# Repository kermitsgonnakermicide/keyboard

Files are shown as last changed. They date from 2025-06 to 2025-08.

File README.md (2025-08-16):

# keyboard

a travel sized 60% keyboard with two rotary encoders for extra functionality!<br>

## Design<br>

This keyboard is pretty **bog-standard**, and can be split into two basic components; the PCB and case<br>
**PCB**:<br>
Fully through hole, with a raspberry pi pico, in4018 diodes and HMX macchiato switches(cheap + sound awesome!)<br>
Went fully THT to keep costs as low as I can, and get some real soldering in!<br>
**Case**:<BR>
Just a case covering the entire keyboard t_t
Again, owing to the purpose of the keyboard, I want to keep it small and simple, but for the shiggles I addded this cool pattern to the bottom of my case<br>
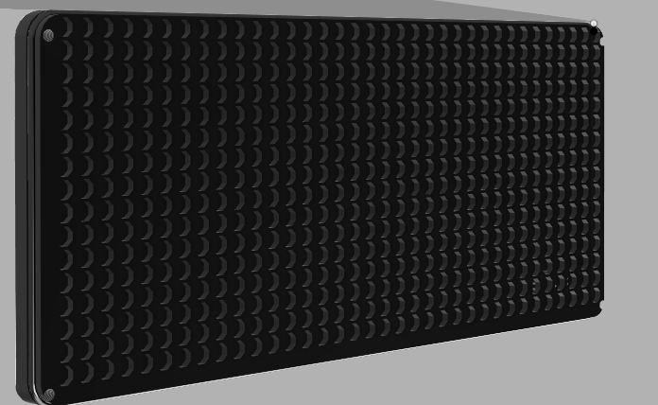
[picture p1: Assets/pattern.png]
<br>

**Firmware**:<br>
Again, pretty standard KMK firmware running on the pico<br>
<br>

## Images

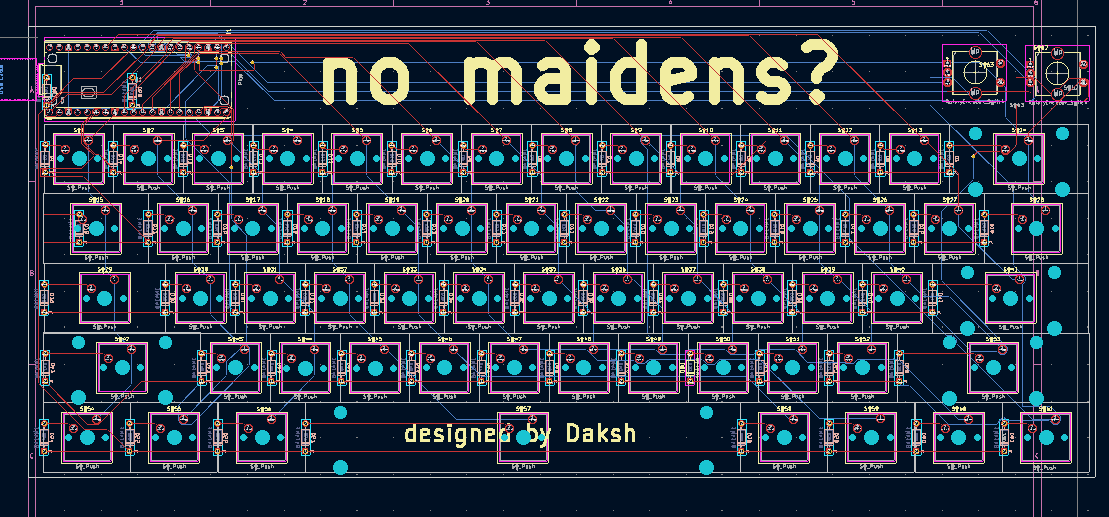
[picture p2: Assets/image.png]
<br>
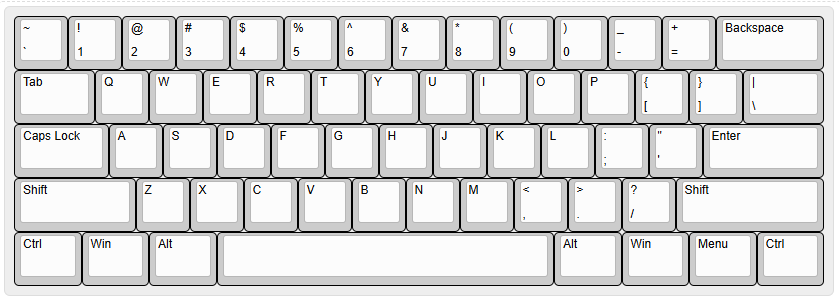
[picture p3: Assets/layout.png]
<br>
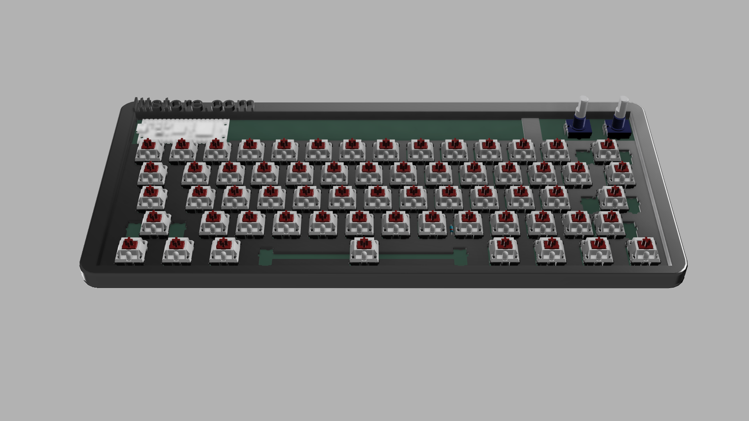
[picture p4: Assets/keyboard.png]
<BR>
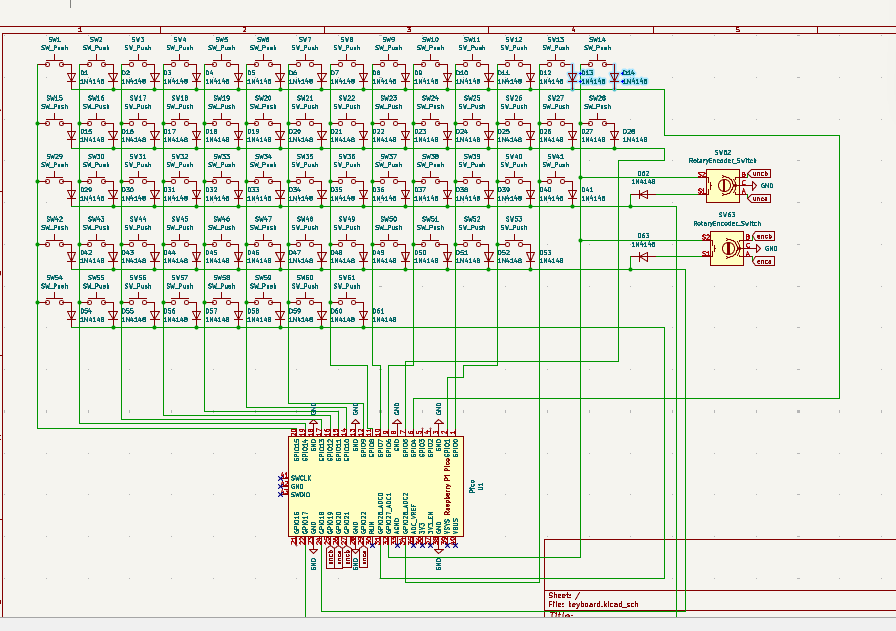
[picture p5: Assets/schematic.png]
<br>

### Images of the CAD

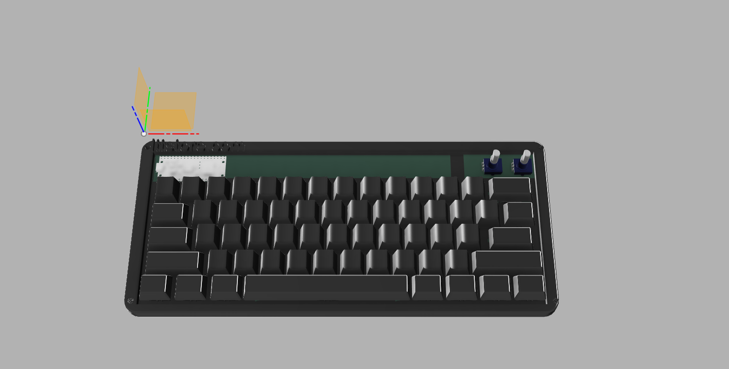
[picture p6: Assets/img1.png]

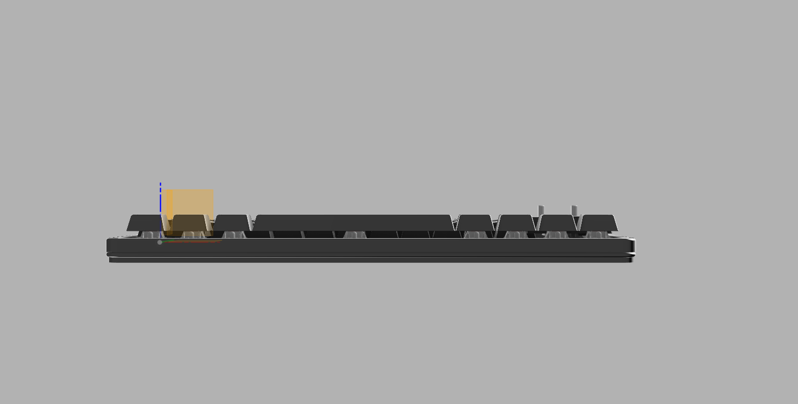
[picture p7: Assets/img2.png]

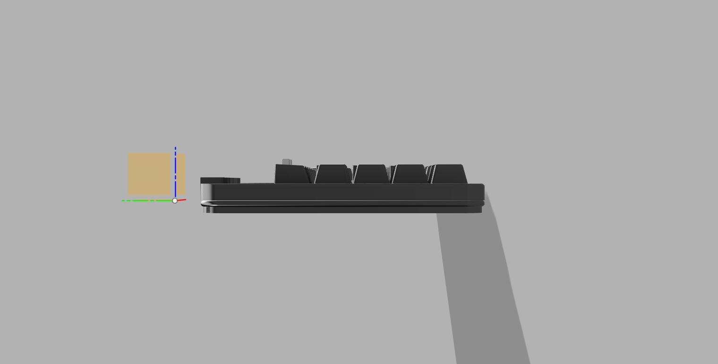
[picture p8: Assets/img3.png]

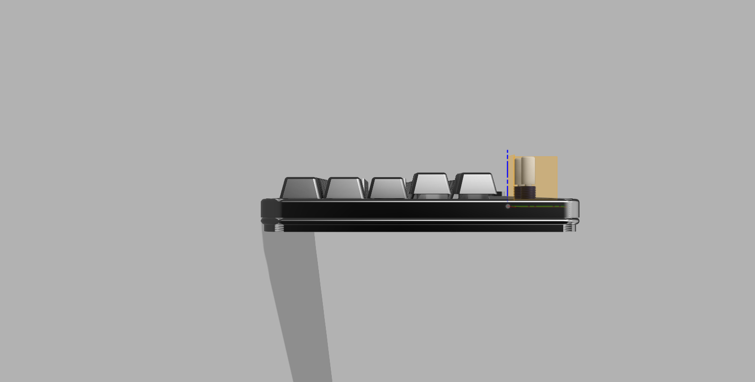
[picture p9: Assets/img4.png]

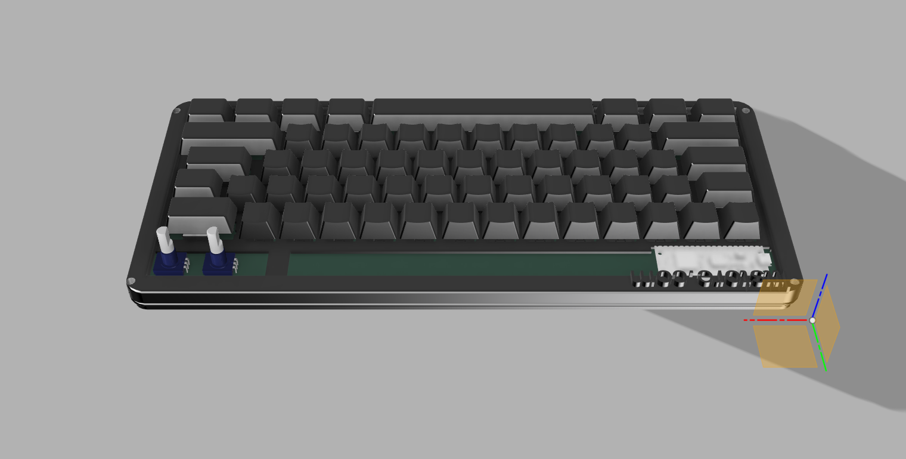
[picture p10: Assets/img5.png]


## BOM

| ITEM | QTY | TOTAL  | SRC | NOTE |
| --- | --- | --- | --- | --- |
| HMX Macchiato Linear Switch | 7 | 24.35  | [https://neomacro.in/products/keykobo-rainbow?variant=48680982413590](https://neomacro.in/products/keykobo-rainbow?variant=48680982413590) | Sold in packs of 10 and I require 62 |
| KeyKobo Rainbow Keycap | 1 | 43.48  | [https://neomacro.in/products/keykobo-rainbow?variant=48680982413590](https://neomacro.in/products/keykobo-rainbow?variant=48680982413590) | |
| Raspberry Pi Pico 2 | 1 | 4.79 | [https://www.amazon.in/Raspberry-Pico-All-Microcontroller-Board/dp/B0B69KZBD8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,aps,281&sr=8-1&th=1](https://www.amazon.in/Raspberry-Pico-All-Microcontroller-Board/dp/B0B69KZBD8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,aps,281&sr=8-1&th=1) | |
| IN4148 diode | 100 | 1.74 | [https://www.amazon.in/100PCS-1N4148-IN4148-switching-Switching/dp/B08DYFFYPQ](https://www.amazon.in/100PCS-1N4148-IN4148-switching-Switching/dp/B08DYFFYPQ) | |
| EC11 Encoder | 2 | 2.06 | [https://www.amazon.in/dp/B0888RVZSN?social_share=cm_sw_r_cp_ud_dp_ECM6496E6Q914JPQP2XQ&\_encoding=UTF8&psc=1](https://www.amazon.in/dp/B0888RVZSN?social_share=cm_sw_r_cp_ud_dp_ECM6496E6Q914JPQP2XQ&_encoding=UTF8&psc=1) | |
| PCB Cost | 1 | 39.55  | JLCPCB | Without coupon, including shipping |
| M5 CSK Screws | 15  | 1.71 | [https://www.amazon.in/RT-SENSE-Countersunk-Machine-tensile/dp/B0CZDXM5NJ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,industrial,263&sr=1-4&th=1](https://www.amazon.in/RT-SENSE-Countersunk-Machine-tensile/dp/B0CZDXM5NJ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,industrial,263&sr=1-4&th=1) | |
| | | | | |
| | | 117.68 | | |

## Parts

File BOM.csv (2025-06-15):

ITEM | QTY | TOTAL | SRC | NOTE
HMX Macchiato Linear Switch | 7 | 24.35 | https://neomacro.in/products/keykobo-rainbow?variant=48680982413590 | Sold in packs of 10 and I require 62
KeyKobo Rainbow Keycap | 1 | 43.48 | https://neomacro.in/products/keykobo-rainbow?variant=48680982413590
Raspberry Pi Pico 2 | 1 | 9.76 | https://www.amazon.in/Raspberry-Microcontroller-Dual-Core-Support-Performance/dp/B0DT983C25
IN4148 diode | 100 | 1.74 | https://www.amazon.in/100PCS-1N4148-IN4148-switching-Switching/dp/B08DYFFYPQ
EC11 Encoder | 2 | 2.06 | https://www.amazon.in/dp/B0888RVZSN
PCB Cost | 1 | 39.55 | JLCPCB | Without coupon, including shipping
M5 CSK Screws | 10 | 0.36
 |  | 121.3

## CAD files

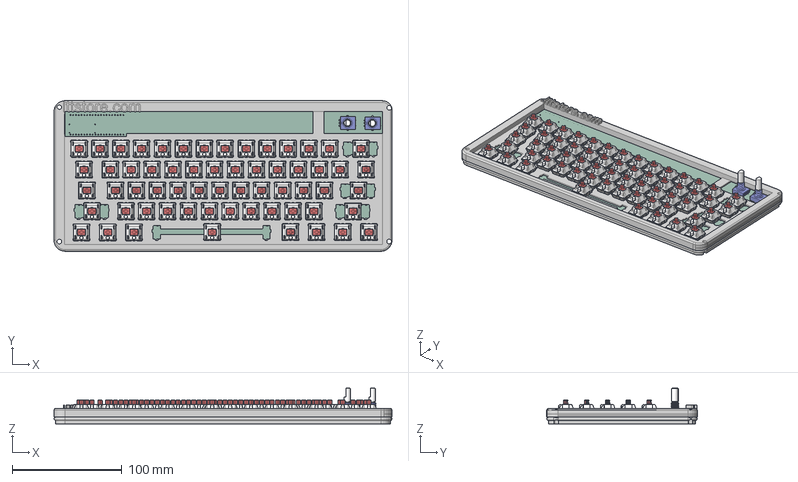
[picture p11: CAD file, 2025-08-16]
keyboard v14.step
308.4 x 137.4 x 32.5 mm
D_DO-35_SOD27_P7.62mm_Horizontal x 63
Bottom x 61
Pulsador x 61
Top x 61
Pieza5^Cherry MX x 61
Pin1 x 61
Pin2 x 61
Led 3mm_trans x 61
Shaft x 2
Pins x 2

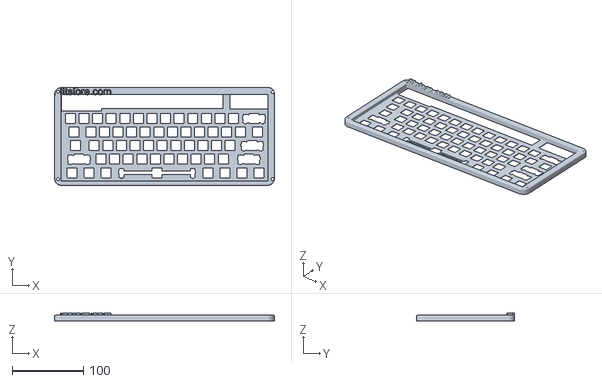
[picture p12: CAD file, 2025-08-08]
Production/top_panel.stl
308.4 x 137.4 x 11.0

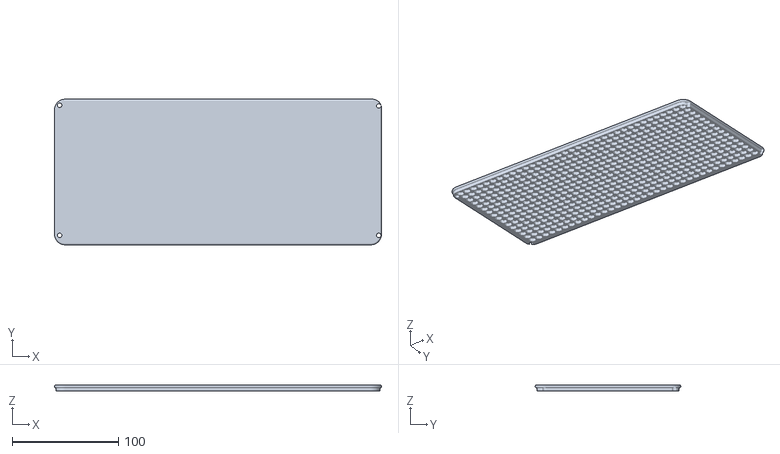
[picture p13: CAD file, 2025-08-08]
Production/bottom_panel.stl
308.4 x 137.4 x 6.00

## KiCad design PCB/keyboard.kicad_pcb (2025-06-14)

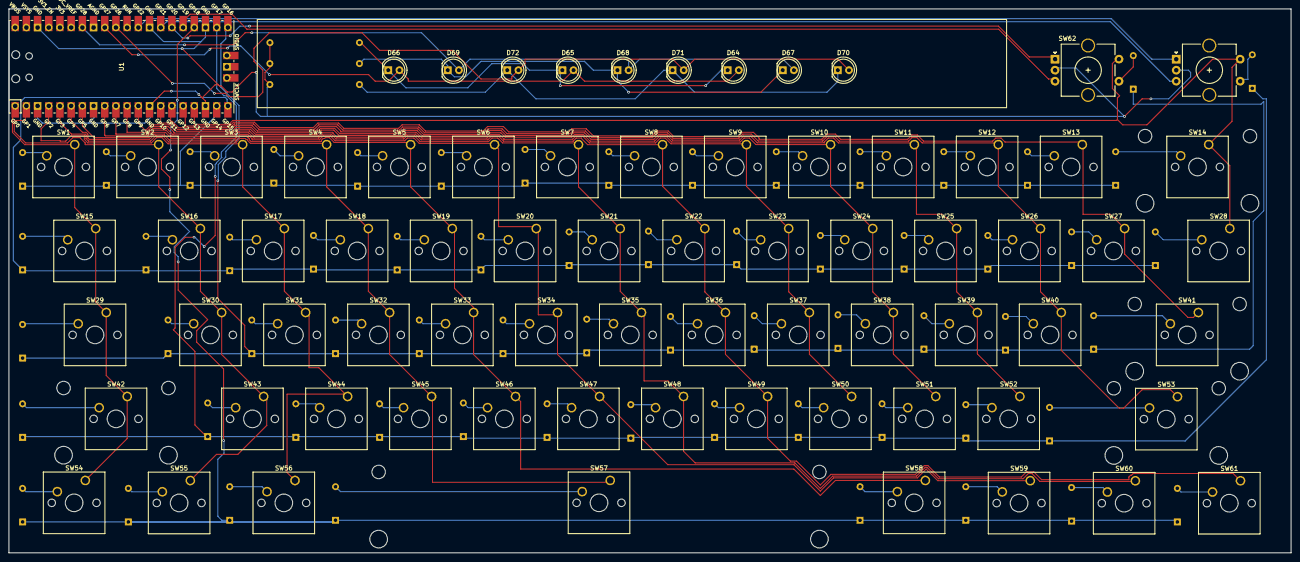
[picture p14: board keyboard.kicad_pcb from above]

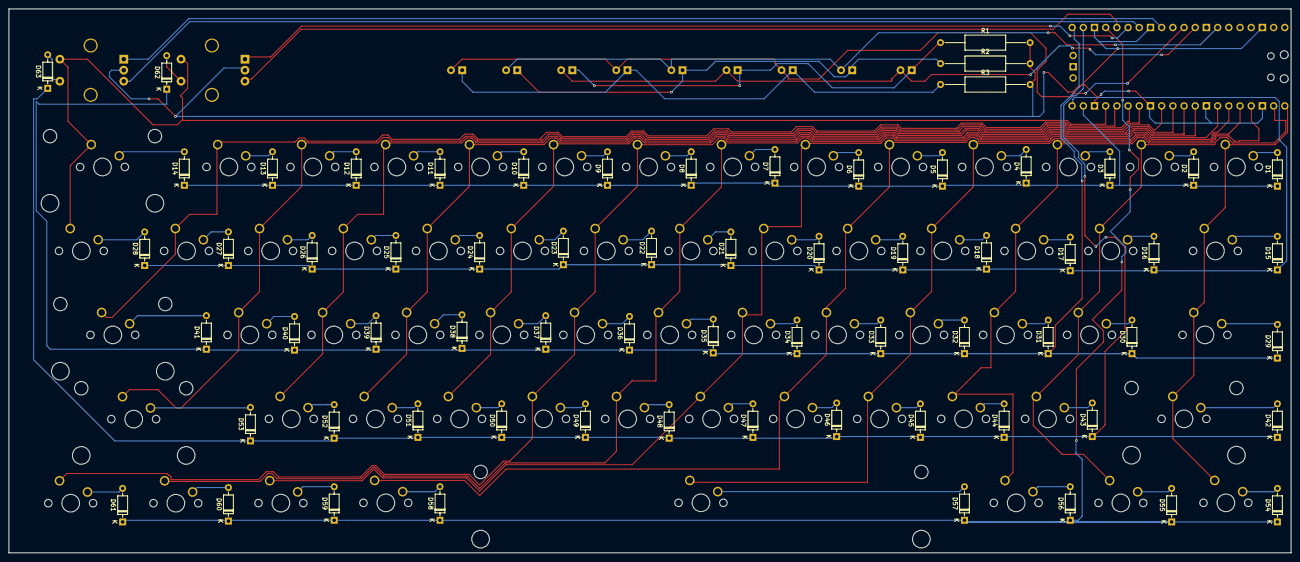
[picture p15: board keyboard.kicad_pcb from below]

Board: 2 copper layers, 290.9 x 123.4 mm, 139 parts (66 on the bottom side), 93 nets.

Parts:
D1, D2, D3, D4, D5, D6, D7, D8, D9, D10, D11, D12, D13, D14, D15, D16, D17, D18, D19, D20, D21, D22, D23, D24, D25, D26, D27, D28, D29, D30, D31, D32, D33, D34, D35, D36, D37, D38, D39, D40, D41, D42, D43, D44, D45, D46, D47, D48, D49, D50, D51, D52, D53, D54, D55, D56, D57, D58, D59, D60, D61, D62, D63: 1N4148; D_DO-35_SOD27_P7.62mm_Horizontal
D64, D65, D66, D67, D68, D69, D70, D71, D72: LED_Small; LED_D5.0mm
R1, R2, R3: 330Ω; R_Axial_DIN0309_L9.0mm_D3.2mm_P20.32mm_Horizontal
SW1, SW2, SW3, SW4, SW5, SW6, SW7, SW8, SW9, SW10, SW11, SW12, SW13, SW16, SW17, SW18, SW19, SW20, SW21, SW22, SW23, SW24, SW25, SW26, SW27, SW30, SW31, SW32, SW33, SW34, SW35, SW36, SW37, SW38, SW39, SW40, SW43, SW44, SW45, SW46, SW47, SW48, SW49, SW50, SW51, SW52: SW_Push; SW_Cherry_MX_1.00u_PCB
SW14: SW_Push; SW_Cherry_MX_2.00u_PCB
SW15, SW28: SW_Push; SW_Cherry_MX_1.50u_PCB
SW29: SW_Push; SW_Cherry_MX_1.75u_PCB
SW41, SW42: SW_Push; SW_Cherry_MX_2.25u_PCB
SW53: SW_Push; SW_Cherry_MX_2.75u_PCB
SW54, SW55, SW56, SW58, SW59, SW60, SW61: SW_Push; SW_Cherry_MX_1.25u_PCB
SW57: SW_Push; SW_Cherry_MX_6.25u_PCB
SW62, SW63: RotaryEncoder_Switch; RotaryEncoder_Alps_EC11E-Switch_Vertical_H20mm_CircularMoun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
U1: Pico; RPi_Pico_SMD_TH

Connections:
GND: R1.2, R2.2, R3.2, SW62.C, SW63.C, U1.3 (GND), U1.8 (GND), U1.13 (GND), U1.18 (GND), U1.23 (GND), U1.28 (GND), U1.38 (GND)
unnamed: D1.2 (A), SW1.2
unnamed: D2.2 (A), SW2.2
unnamed: D3.2 (A), SW3.2
unnamed: D4.2 (A), SW4.2
unnamed: D5.2 (A), SW5.2
unnamed: D6.2 (A), SW6.2
unnamed: D7.2 (A), SW7.2
unnamed: D8.2 (A), SW8.2
unnamed: D9.2 (A), SW9.2
unnamed: D10.2 (A), SW10.2
unnamed: D11.2 (A), SW11.2
unnamed: D12.2 (A), SW12.2
unnamed: D13.2 (A), SW13.2
unnamed: D14.2 (A), SW14.2
unnamed: D15.2 (A), SW15.2
unnamed: D16.2 (A), SW16.2
unnamed: D17.2 (A), SW17.2
unnamed: D18.2 (A), SW18.2
unnamed: D19.2 (A), SW19.2
unnamed: D20.2 (A), SW20.2
unnamed: D21.2 (A), SW21.2
unnamed: D22.2 (A), SW22.2
unnamed: D23.2 (A), SW23.2
unnamed: D24.2 (A), SW24.2
unnamed: D25.2 (A), SW25.2
unnamed: D26.2 (A), SW26.2
unnamed: D27.2 (A), SW27.2
unnamed: D28.2 (A), SW28.2
unnamed: D29.2 (A), SW29.2
unnamed: D30.2 (A), SW30.2
unnamed: D31.2 (A), SW31.2
unnamed: D32.2 (A), SW32.2
unnamed: D33.2 (A), SW33.2
unnamed: D34.2 (A), SW34.2
unnamed: D35.2 (A), SW35.2
unnamed: D36.2 (A), SW36.2
unnamed: D37.2 (A), SW37.2
unnamed: D38.2 (A), SW38.2
unnamed: D39.2 (A), SW39.2
unnamed: D40.2 (A), SW40.2
unnamed: D41.2 (A), SW41.2
unnamed: D42.2 (A), SW42.2
unnamed: D43.2 (A), SW43.2
unnamed: D44.2 (A), SW44.2
unnamed: D45.2 (A), SW45.2
unnamed: D46.2 (A), SW46.2
unnamed: D47.2 (A), SW47.2
unnamed: D48.2 (A), SW48.2
unnamed: D49.2 (A), SW49.2
unnamed: D50.2 (A), SW50.2
unnamed: D51.2 (A), SW51.2
unnamed: D52.2 (A), SW52.2
unnamed: D53.2 (A), SW53.2
unnamed: D54.2 (A), SW54.2
unnamed: D55.2 (A), SW55.2
unnamed: D56.2 (A), SW56.2
unnamed: D57.2 (A), SW57.2
unnamed: D58.2 (A), SW58.2
unnamed: D59.2 (A), SW59.2
unnamed: D60.2 (A), SW60.2
unnamed: D61.2 (A), SW61.2
unnamed: D62.2 (A), SW62.S1
unnamed: D63.2 (A), SW63.S1
unnamed: D64.1 (K), D65.1 (K), D66.1 (K), R1.1
unnamed: D67.1 (K), D68.1 (K), D69.1 (K), R2.1
unnamed: D70.1 (K), D71.1 (K), D72.1 (K), R3.1
blue_anode: D67.2 (A), D68.2 (A), D69.2 (A), U1.34 (GPIO28_ADC2)
col1: SW1.1, SW15.1, SW29.1, SW42.1, SW54.1, U1.1 (GPIO0)
col2: SW2.1, SW16.1, SW30.1, SW43.1, SW55.1, U1.2 (GPIO1)
col3: SW3.1, SW17.1, SW31.1, SW44.1, SW56.1, U1.4 (GPIO2)
col4: SW4.1, SW18.1, SW32.1, SW45.1, SW57.1, U1.5 (GPIO3)
col5: SW5.1, SW19.1, SW33.1, SW46.1, SW58.1, U1.6 (GPIO4)
col6: SW6.1, SW20.1, SW34.1, SW47.1, SW59.1, U1.7 (GPIO5)
col7: SW7.1, SW21.1, SW35.1, SW48.1, SW60.1, U1.9 (GPIO6)
col8: SW8.1, SW22.1, SW36.1, SW49.1, SW61.1, U1.10 (GPIO7)
col9: SW9.1, SW23.1, SW37.1, SW50.1, U1.11 (GPIO8)
col10: SW10.1, SW24.1, SW38.1, SW51.1, U1.12 (GPIO9)
col11: SW11.1, SW25.1, SW39.1, SW52.1, U1.14 (GPIO10)
col12: SW12.1, SW26.1, SW40.1, SW53.1, U1.15 (GPIO11)
col13: SW13.1, SW27.1, SW41.1, U1.16 (GPIO12)
col14: SW14.1, SW28.1, SW62.S2, SW63.S2, U1.17 (GPIO13)
green_anode: D70.2 (A), D71.2 (A), D72.2 (A), U1.31 (GPIO26_ADC0)
re1: SW62.B, U1.25 (GPIO19)
re2: SW62.A, U1.26 (GPIO20)
re3: SW63.B, U1.27 (GPIO21)
re4: SW63.A, U1.29 (GPIO22)
red_anode: D64.2 (A), D65.2 (A), D66.2 (A), U1.32 (GPIO27_ADC1)
row1: D1.1 (K), D2.1 (K), D3.1 (K), D4.1 (K), D5.1 (K), D6.1 (K), D7.1 (K), D8.1 (K), D9.1 (K), D10.1 (K), D11.1 (K), D12.1 (K), D13.1 (K), D14.1 (K), U1.19 (GPIO14)
row2: D15.1 (K), D16.1 (K), D17.1 (K), D18.1 (K), D19.1 (K), D20.1 (K), D21.1 (K), D22.1 (K), D23.1 (K), D24.1 (K), D25.1 (K), D26.1 (K), D27.1 (K), D28.1 (K), U1.20 (GPIO15)
row3: D29.1 (K), D30.1 (K), D31.1 (K), D32.1 (K), D33.1 (K), D34.1 (K), D35.1 (K), D36.1 (K), D37.1 (K), D38.1 (K), D39.1 (K), D40.1 (K), D41.1 (K), D62.1 (K), U1.21 (GPIO16)
row4: D42.1 (K), D43.1 (K), D44.1 (K), D45.1 (K), D46.1 (K), D47.1 (K), D48.1 (K), D49.1 (K), D50.1 (K), D51.1 (K), D52.1 (K), D53.1 (K), D63.1 (K), U1.22 (GPIO17)
row5: D54.1 (K), D55.1 (K), D56.1 (K), D57.1 (K), D58.1 (K), D59.1 (K), D60.1 (K), D61.1 (K), U1.24 (GPIO18)

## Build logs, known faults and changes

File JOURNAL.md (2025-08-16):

**Total Time Spent: 16hr**

# Day 1 - June 13th(PT1)

I decided on a 60% layout, as I wanted this to travel w/ me. I used the default 60% from keyboardlayout <br>
<br>
I also made the schematic for this<br>
<br>
I wanted this keyboard to have two encoders; one for volume dialing and one for general page navigation, so I put them both there<br>
I did use a diode matrix, with through-hole diodes as I wanted to hand-solder this.<BR>
Still not sure on which switches to use, but i'm certain I want something creamy/thocky. Would love to use milky whites or oil kings
**Total Time spent: 4hr**

# Day 2 - June 13th(PT2)

Today, I also routed the PCB for this -<br>
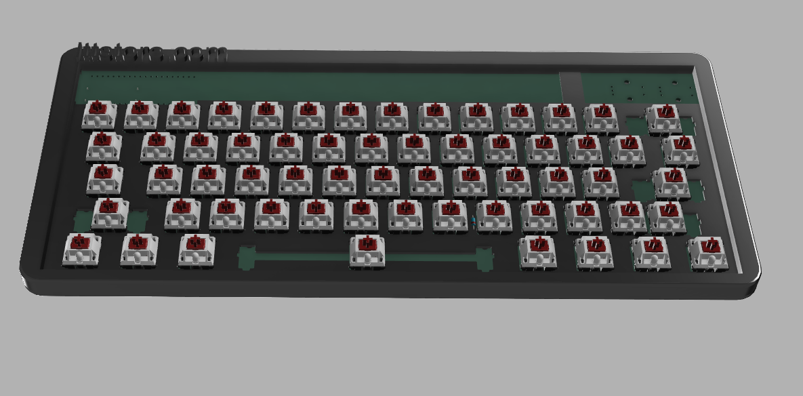
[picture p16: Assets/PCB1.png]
 <br>
Again, I wanted to keep it small as this is a travel keyboard so the dimensions are 292x124mm<br>
This is a rather 'no frills' keyboard - i just want nice switches and a couple encoders and NOTHING else
**Time Spent: 6hr**

# Day 3 - June 14th

Today, I made the case<br>
aaa
The case is(yet again) rather simple, with a couple of slots for m5 size screws to hold the case in place.<br>
Other than that, nothing remarkable except for the fact I intend to use ABS for its durability(remember, this is a travel keyboard)<br>
Additionally, I finally settled on a [switch](https://neomacro.in/products/hmx-macchiato-linear-switch), which is the HMX macchiato and some [keycaps](https://stackskb.com/store/stackspbt-lavender-mda-profile-keycaps-131-key/)
I intend to work on the firmware and _hopefully_ ship it by EOTD<br>
**Time Spent: 3hr30**<br>

# Day 3(pt2)

Firmware was a pretty basic KMK script - everything w/ encoder and keys<br>
Essentially, it uses the row-column diode matrix, same thing with the encoder<br>
KMK runs on Adafruit's circuit python, which will in turn run on my pico
**Time Spent: 1hr30**

# Day 4 - August 16th

Made the cad a little better! Added the keycaps and also a nice hexagon pattern<br>
<br>
The keycaps are for added realism, while the hexagon is just to make the case look cooler<br>






**Time Spent: 1hr**

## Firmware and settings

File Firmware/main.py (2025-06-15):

import board
import time

from kmk.kmk_keyboard import KMKKeyboard
from kmk.keys import KC
from kmk.scanners import DiodeOrientation

from kmk.modules.encoder import EncoderHandler
from kmk.modules.mouse_keys import MouseKeys
from kmk.extensions.media_keys import MediaKeys
from kmk.modules.macros import Macros

keyboard = KMKKeyboard()

keyboard.extensions.append(MediaKeys())
keyboard.modules.append(MouseKeys())

macros = Macros()
keyboard.modules.append(macros)

encoder_handler = EncoderHandler()
keyboard.modules.append(encoder_handler)

keyboard.col_pins = (
    board.GP0, board.GP1, board.GP2, board.GP3, board.GP4, board.GP5, board.GP6,
    board.GP7, board.GP8, board.GP9, board.GP10, board.GP11, board.GP12, board.GP13
)
keyboard.row_pins = (board.GP14, board.GP15, board.GP16, board.GP17, board.GP18)
keyboard.diode_orientation = DiodeOrientation.ROW2COL

encoder_handler.pins = (
    (board.GP19, board.GP20),
    (board.GP21, board.GP22),
)
encoder_handler.map = [
    ((KC.VOLD, KC.VOLU),),
    ((KC.MPRV, KC.MNXT),),
]

current = 0

@macros.add(KC.X)
def change():
    global current
    current = (current + 1) % 3

keyboard.keymap = [
    [
        KC.ESC, KC.Q, KC.W, KC.E, KC.R, KC.T, KC.Y, KC.U, KC.I, KC.O, KC.P, KC.BSPC, KC.NO, KC.NO,
        KC.TAB, KC.A, KC.S, KC.D, KC.F, KC.G, KC.H, KC.J, KC.K, KC.L, KC.ENT, KC.NO, KC.NO, KC.NO,
        KC.LSFT, KC.Z, KC.X, KC.C, KC.V, KC.B, KC.N, KC.M, KC.COMM, KC.DOT, KC.UP, KC.NO, KC.NO, KC.NO,
        KC.LCTL, KC.LGUI, KC.LALT, KC.SPC, KC.RALT, KC.LEFT, KC.DOWN, KC.RIGHT, KC.NO, KC.NO, KC.NO, KC.NO, KC.NO, KC.NO,
    ]
]

if __name__ == '__main__':
    keyboard.go()

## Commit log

2025-06-14 UGHGHG why doesnt my pcb ffile work
2025-06-14 production stuff
    [keyboard-B_Cu.gbr, keyboard-B_Mask.gbr, keyboard-B_Paste.gbr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]
